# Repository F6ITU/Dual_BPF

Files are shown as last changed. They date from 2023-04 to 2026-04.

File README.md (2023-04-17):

# Alexiares dual BPF for Orion/Anvelina SDR Board

1 to 60 MHz Band pass filter for dual ADC SDR  (Orion class, Anvelina, Red Pitaya)

This pcb serves as RX bandpass for the new generation of Alexiares frontend

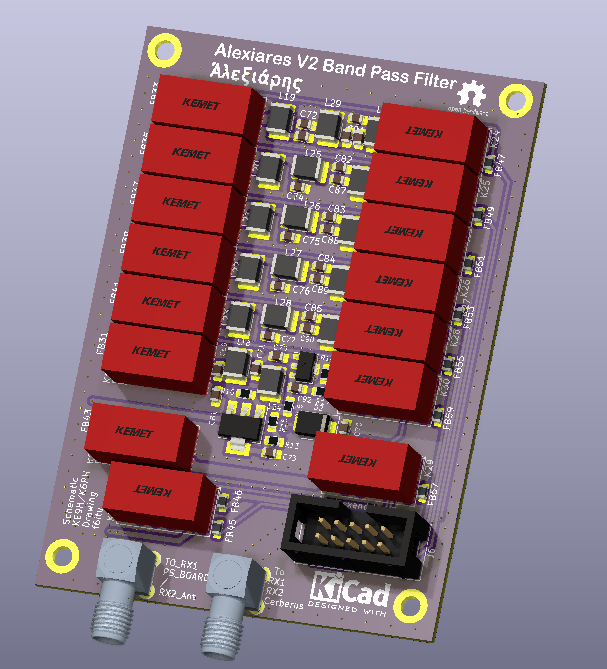
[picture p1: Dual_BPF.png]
Alex BPF V1


It replace the former Alexiares HPF filter and uses the very same SPI bus protocol

Please note that on BPF1  

K23, FB45, FB46, R11, R12, C106 and C93 should NOT be soldered

 (pads 3-10 and 9-4 should be strapped)
 
Signal RX2_GND is not used

BPF2 should be fully assembled, with K23, FB45, FB46, R11, R12, C106 and C93. Signal RX2_GND should be present on J6

(see Alexandrie V2 wirering )

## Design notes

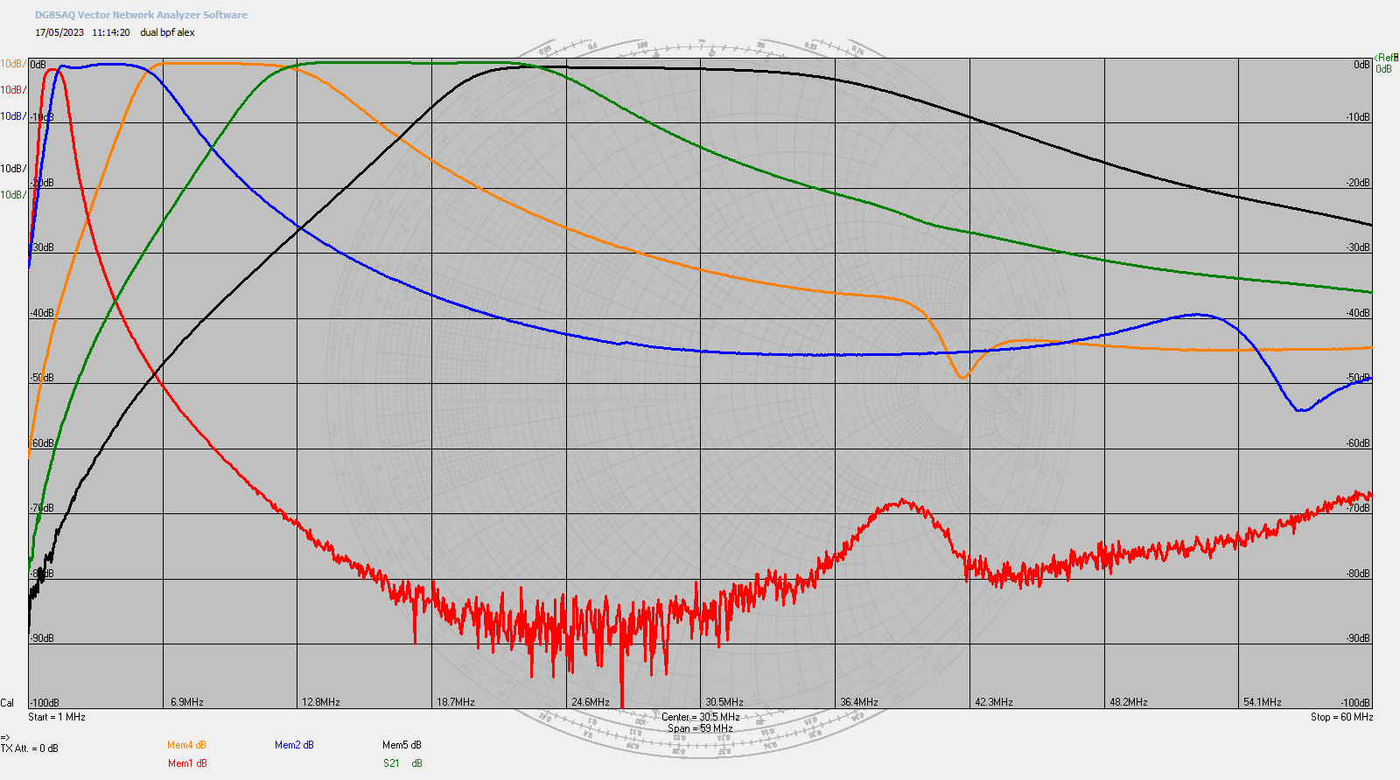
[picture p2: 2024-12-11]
documentation/Dual_bpf_alex_amplitude.png

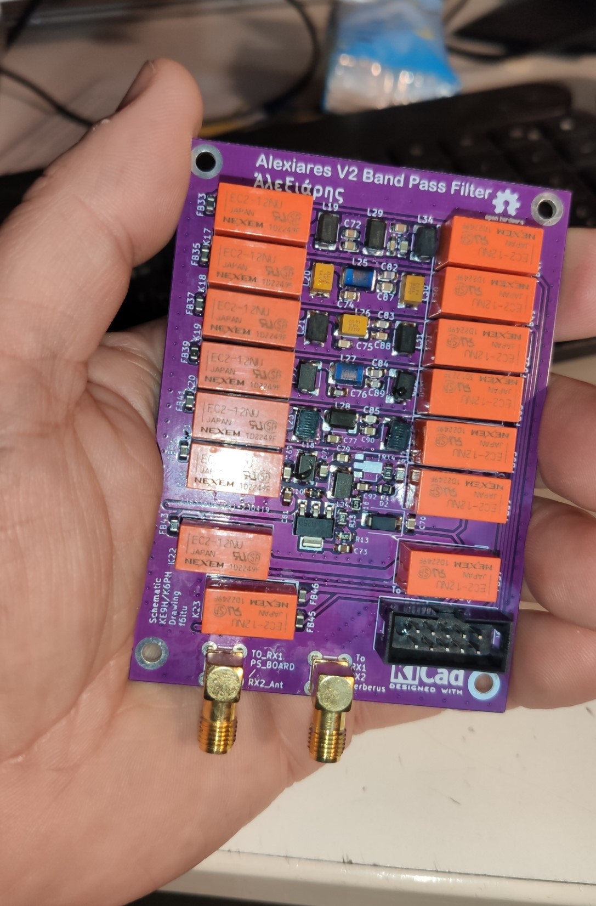
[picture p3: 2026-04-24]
documentation/Dual_bandpass_filter.jpg

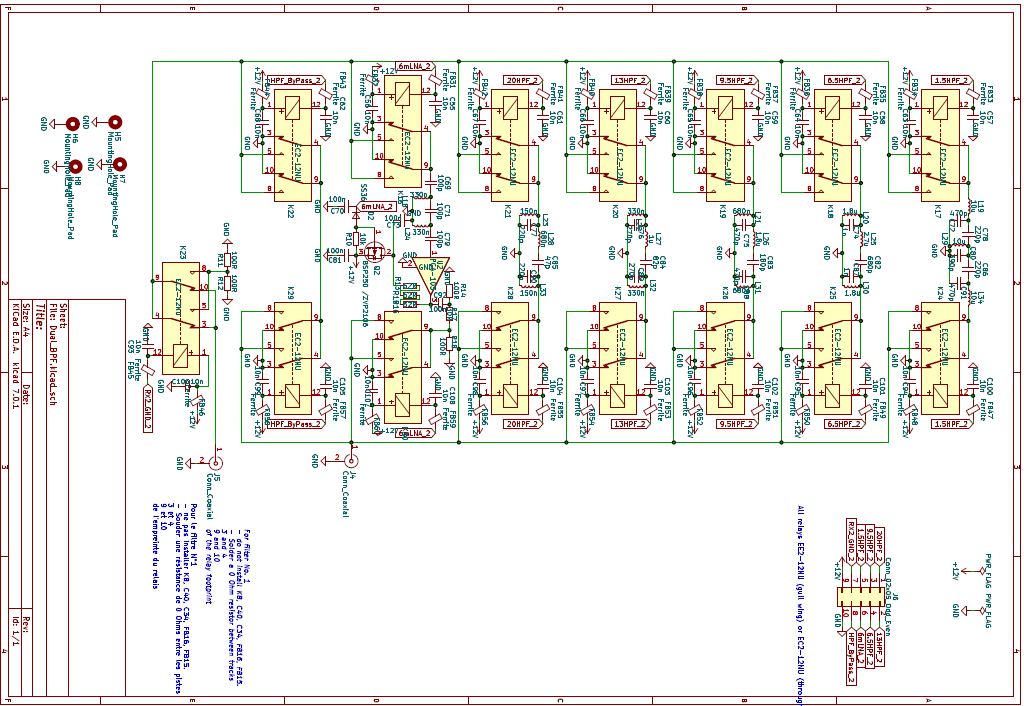
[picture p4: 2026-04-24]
documentation/Dual_bpf.png

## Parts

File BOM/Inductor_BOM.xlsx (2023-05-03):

inductance | ref mouser | form factor | Qty/brd | PU | Price 2 filters
330n | 279-3613CR33M | 1812 | 4 | 0,60 | 4.8 | x8
150n | 994-1812SMS-R15JLC | 1812 | 2 | 2,11 | 8.44 | X4
680n | 807-1812R-681K | 1812 | 3 | 1,88 | 11.28 | x6
1u | 994-1812CS-102XJLC | 1812 | 1 | 1,17 | 2.34 | x2
1.8u | 70-IMC1812RQ1R8J | 1812 | 3 | 0,71 | 4.26 | x6
2.7u | 1812CS-272XJLC (https://www.mouser.fr/ProductDetail/Coilcraft/1812CS-272XJLC?qs=zCSbvcPd3pb%2FoQoml91VxA%3D%3D) | 1812 | 1 | 1,17 | 2.34 | x2
10u | 807-1812R-103J | 1812 | 3 | 2,53 | 15.18 | x6
Relays |  |  | 17
EC-12NU | 80-EC2-12NU |  | 15 | 1,85 | 55.5 | x30.. Envisager x100 à 166€
filters
 | 139-RLP-50 | GP731 |  | 16,33 | 100 | (x10 pour Cerbère et dupli)
semi-conductors
CDSOD323-T03S | 652-CDSOD323-T03S | SOD-323-2 | 1 | 0,62 | 5.48 | (x10 stock)
BSP250 | 771-BSP250135 | SOT-223-3 | 1 | 0,62 | 5.47 | (x10 stock)
PGA103+ | 139-PGA-103 | SOT-89-4 | 1 | 12,54 | 25.08 | x2 | en stock
AFT05MP075NR1 | 841-AFT05MP075NR1 | TO-270-WB-4 | 1 | 19,70 | 39.4
 |  |  |  |  | 279.57 |  | pas nécessaire

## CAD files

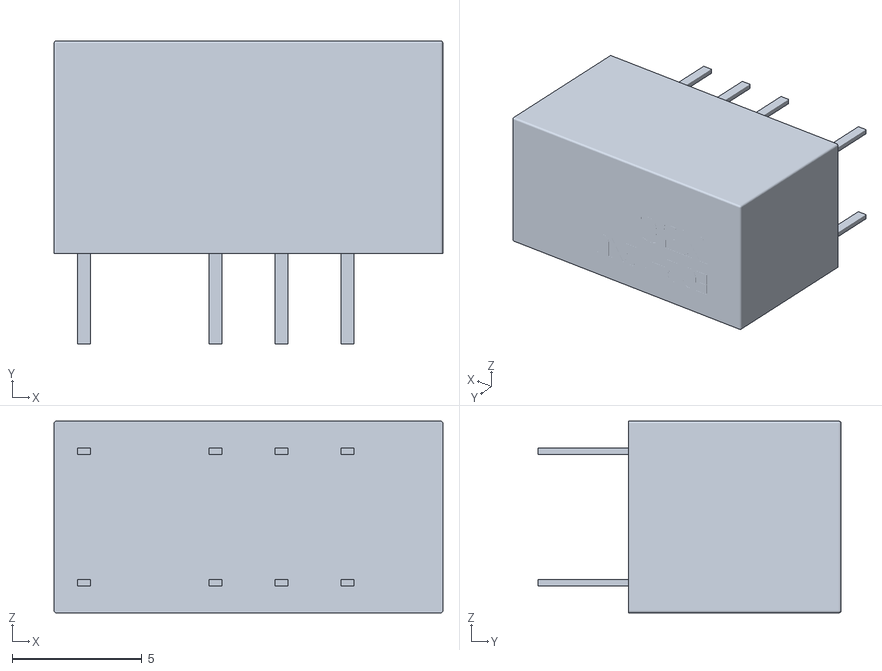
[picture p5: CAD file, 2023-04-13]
documentation/User Library-EC2-12.STL
15.0 x 11.7 x 7.40

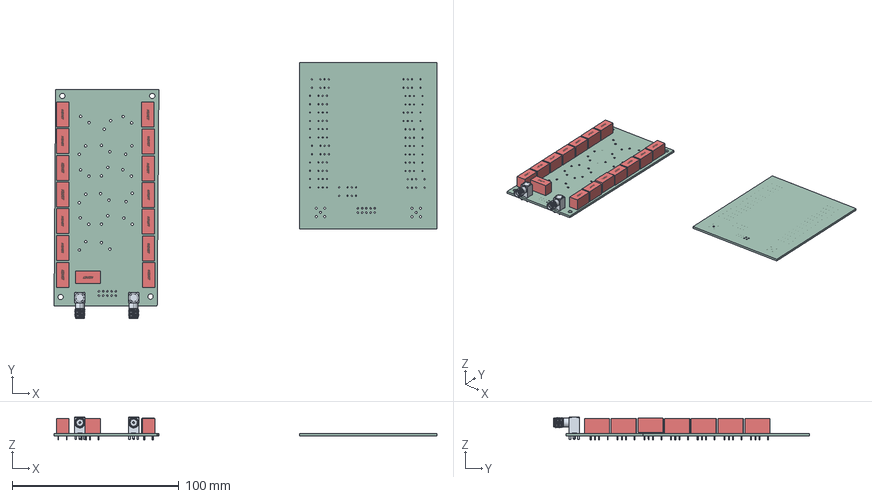
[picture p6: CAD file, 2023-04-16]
Dual_BPF.step
230.0 x 153.5 x 13.8 mm
PCB1
PCB2

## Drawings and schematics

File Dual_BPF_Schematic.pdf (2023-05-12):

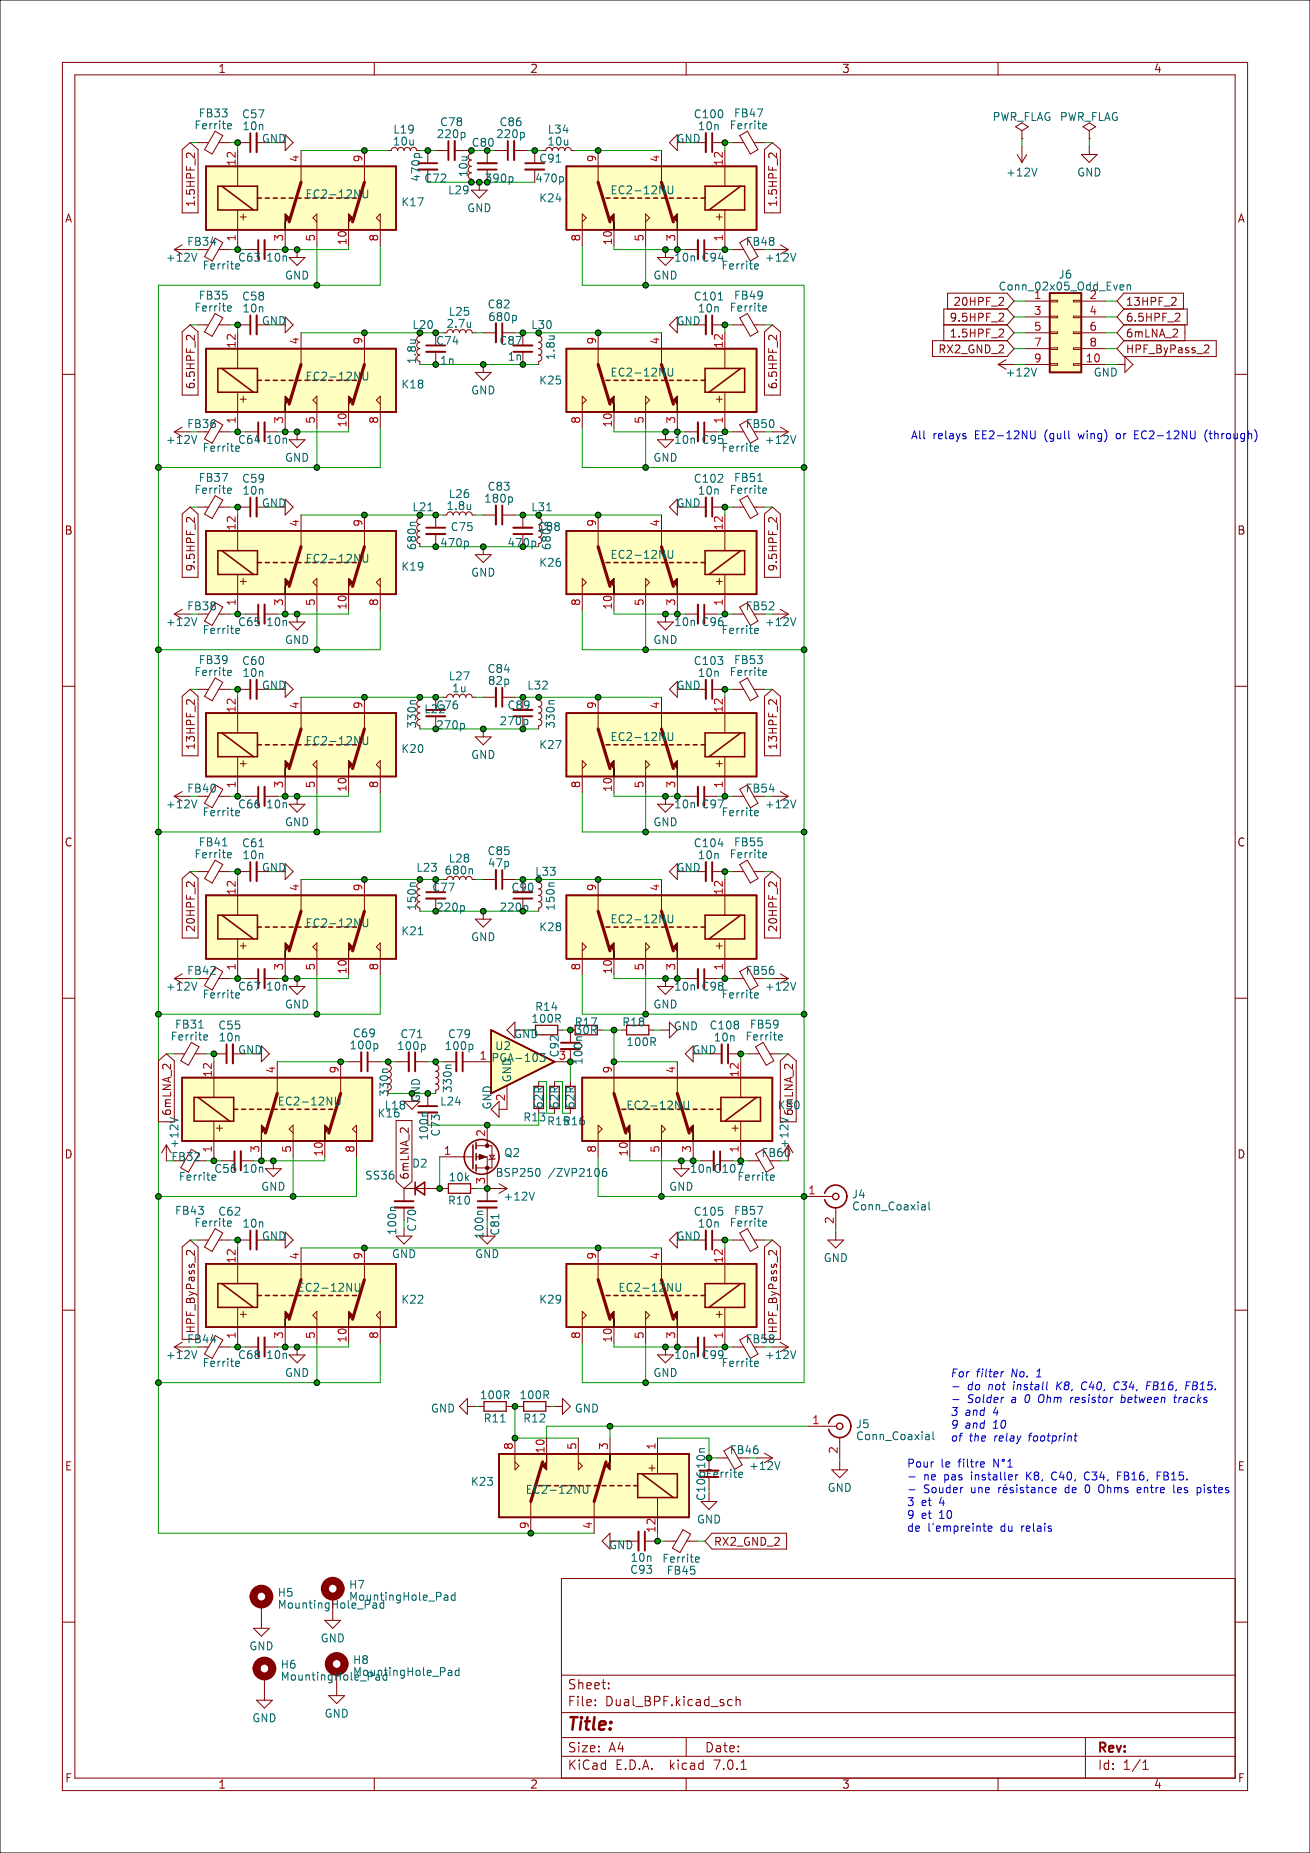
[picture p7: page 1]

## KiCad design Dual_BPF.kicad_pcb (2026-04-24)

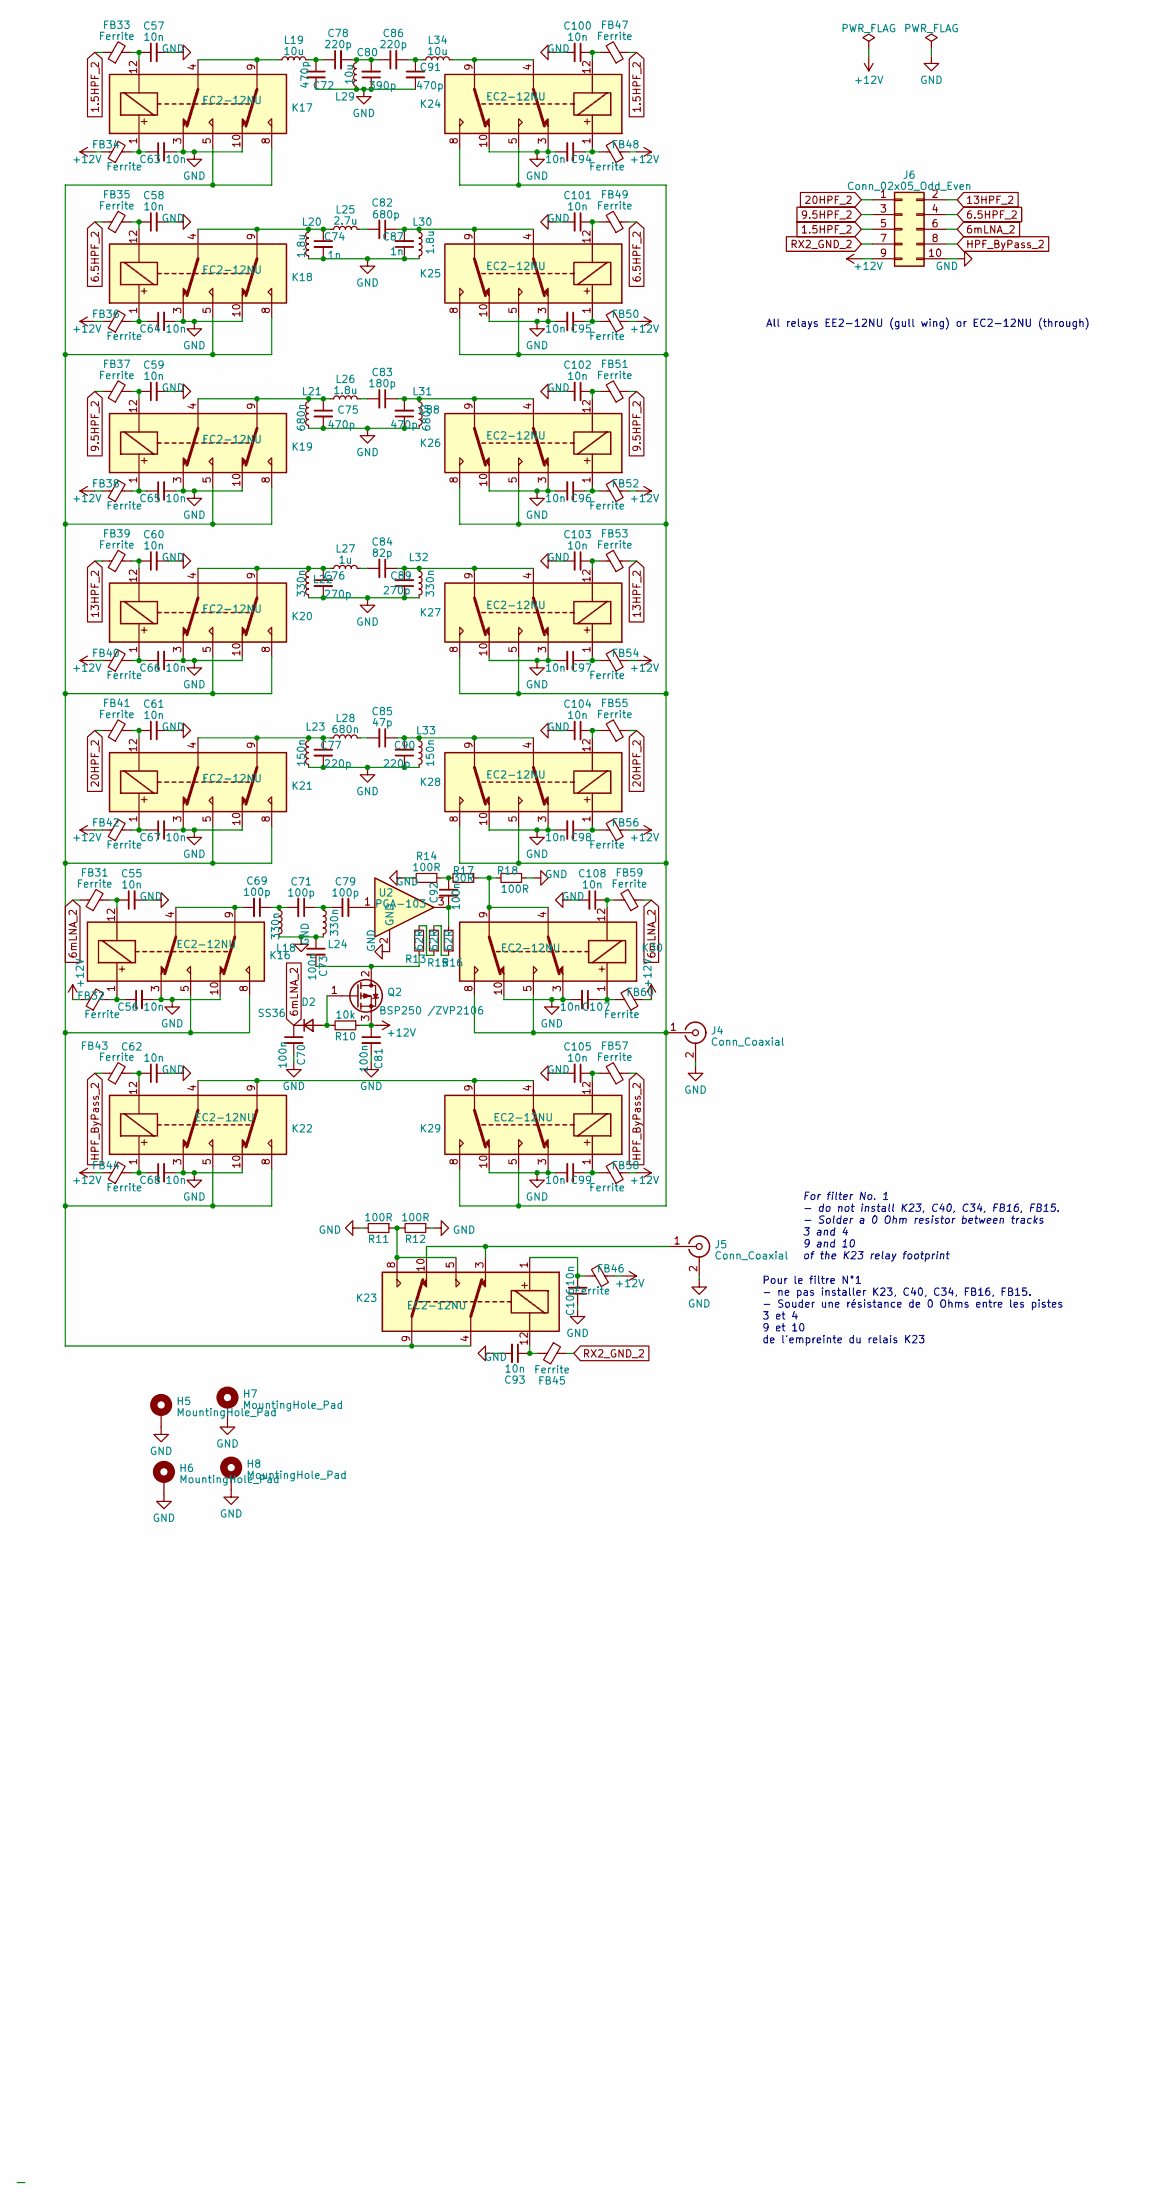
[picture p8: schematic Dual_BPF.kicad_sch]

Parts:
C55, C56, C57, C58, C59, C60, C61, C62, C63, C64, C65, C66, C67, C68, C93, C94, C95, C96, C97, C98, C99, C100, C101, C102, C103, C104, C105, C106, C107, C108: 10n; C_0805_2012Metric_Pad1.18x1.45mm_HandSolder
C69, C71, C79: 100p; C_0805_2012Metric_Pad1.18x1.45mm_HandSolder
C70, C73, C81, C92: 100n; C_0805_2012Metric_Pad1.18x1.45mm_HandSolder
C72, C75, C88, C91: 470p; C_0805_2012Metric_Pad1.18x1.45mm_HandSolder
C74, C87: 1n; C_0805_2012Metric_Pad1.18x1.45mm_HandSolder
C76, C89: 270p; C_0805_2012Metric_Pad1.18x1.45mm_HandSolder
C77, C78, C86, C90: 220p; C_0805_2012Metric_Pad1.18x1.45mm_HandSolder
C80: 390p; C_0805_2012Metric_Pad1.18x1.45mm_HandSolder
C82: 680p; C_0805_2012Metric_Pad1.18x1.45mm_HandSolder
C83: 180p; C_0805_2012Metric_Pad1.18x1.45mm_HandSolder
C84: 82p; C_0805_2012Metric_Pad1.18x1.45mm_HandSolder
C85: 47p; C_0805_2012Metric_Pad1.18x1.45mm_HandSolder
D2: SS36; D_SMB
FB31, FB32, FB33, FB34, FB35, FB36, FB37, FB38, FB39, FB40, FB41, FB42, FB43, FB44, FB45, FB46, FB47, FB48, FB49, FB50, FB51, FB52, FB53, FB54, FB55, FB56, FB57, FB58, FB59, FB60: Ferrite; L_0805_2012Metric
H5, H6, H7, H8: MountingHole_Pad; MountingHole_3.2mm_M3_ISO14580_Pad
J4, J5: Conn_Coaxial; SMA_PINS
J6: Conn_02x05_Odd_Even; IDC-Header_2x05_P2.54mm_Vertical
K16, K17, K18, K19, K20, K21, K22, K23, K24, K25, K26, K27, K28, K29, K30: EC2-12NU; Relay_DPDT_Kemet_EC2
L18, L22, L24, L32: 330n; L_1812_4532Metric_Pad1.30x3.40mm_HandSolder
L19, L29, L34: 10u; L_1812_4532Metric_Pad1.30x3.40mm_HandSolder
L20, L26, L30: 1.8u; L_1812_4532Metric_Pad1.30x3.40mm_HandSolder
L21, L28, L31: 680n; L_1812_4532Metric_Pad1.30x3.40mm_HandSolder
L23, L33: 150n; L_1812_4532Metric_Pad1.30x3.40mm_HandSolder
L25: 2.7u; L_1812_4532Metric_Pad1.30x3.40mm_HandSolder
L27: 1u; L_1812_4532Metric_Pad1.30x3.40mm_HandSolder
Q2: BSP250 /ZVP2106; SOT-223-3_TabPin2
R10: 10k; R_0805_2012Metric_Pad1.20x1.40mm_HandSolder
R11, R12, R14, R18: 100R; R_0805_2012Metric_Pad1.20x1.40mm_HandSolder
R13, R15, R16: 62R; R_0805_2012Metric_Pad1.20x1.40mm_HandSolder
R17: 30R; R_0805_2012Metric_Pad1.20x1.40mm_HandSolder
U2: PGA-103; SOT-89-3

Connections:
1.5HPF_2: FB33.1, FB47.1, J6.5
6.5HPF_2: FB35.1, FB49.1, J6.4
6mLNA_2: C70.1, D2.1 (K), FB31.1, FB59.1, J6.6
9.5HPF_2: FB37.1, FB51.1, J6.3
13HPF_2: FB39.1, FB53.1, J6.2
20HPF_2: FB41.1, FB55.1, J6.1
+12V: C81.1, FB32.1, FB34.1, FB36.1, FB38.1, FB40.1, FB42.1, FB44.1, FB46.1, FB48.1, FB50.1, FB52.1, FB54.1, FB56.1, FB58.1, FB60.1, J6.9, Q2.3 (S), R10.1
GND: C55.2, C56.2, C57.2, C58.2, C59.2, C60.2, C61.2, C62.2, C63.2, C64.2, C65.2, C66.2, C67.2, C68.2, C70.2, C72.2, C73.1, C74.2, C75.2, C76.2, C77.2, C80.1, C81.2, C87.1, C88.1, C89.1, C90.1, C91.2, C93.2, C94.2, C95.2, C96.2, C97.2, C98.2, C99.2, C100.2, C101.2, C102.2, C103.2, C104.2, C105.2, C106.1, C107.2, C108.2, H5.1, H6.1, H7.1, H8.1, J4.2 (Ext), J5.2 (Ext), J6.10, K16.3, K16.10, K17.3, K17.10, K18.3, K18.10, K19.3, K19.10, K20.3, K20.10, K21.3, K21.10, K22.3, K22.10, K24.3, K24.10, K25.3, K25.10, K26.3, K26.10, K27.3, K27.10, K28.3, K28.10, K29.3, K29.10, K30.3, K30.10, L18.2, L20.1, L21.1, L22.1, L23.1, L24.2, L29.2, L30.2, L31.2, L32.2, L33.2, R11.2, R12.1, R14.2, R18.1, U2.2 (GND)
HPF_ByPass_2: FB43.1, FB57.1, J6.8
unnamed: C55.1, FB31.2, K16.12
unnamed: C56.1, FB32.2, K16.1
unnamed: C57.1, FB33.2, K17.12
unnamed: C58.1, FB35.2, K18.12
unnamed: C59.1, FB37.2, K19.12
unnamed: C60.1, FB39.2, K20.12
unnamed: C61.1, FB41.2, K21.12
unnamed: C62.1, FB43.2, K22.12
unnamed: C63.1, FB34.2, K17.1
unnamed: C64.1, FB36.2, K18.1
unnamed: C65.1, FB38.2, K19.1
unnamed: C66.1, FB40.2, K20.1
unnamed: C67.1, FB42.2, K21.1
unnamed: C68.1, FB44.2, K22.1
unnamed: C69.1, C71.2, L18.1
unnamed: C69.2, K16.4, K16.9
unnamed: C71.1, C79.2, L24.1
unnamed: C72.1, C78.1, L19.1
unnamed: C74.1, K18.4, K18.9, L20.2, L25.1
unnamed: C75.1, K19.4, K19.9, L21.2, L26.1
unnamed: C76.1, K20.4, K20.9, L22.2, L27.1
unnamed: C77.1, K21.4, K21.9, L23.2, L28.1
unnamed: C78.2, C80.2, C86.1, L29.1
unnamed: C79.1, U2.1
unnamed: C82.1, C87.2, K25.4, K25.9, L30.1
unnamed: C82.2, L25.2
unnamed: C83.1, C88.2, K26.4, K26.9, L31.1
unnamed: C83.2, L26.2
unnamed: C84.1, C89.2, K27.4, K27.9, L32.1
unnamed: C84.2, L27.2
unnamed: C85.1, C90.2, K28.4, K28.9, L33.1
unnamed: C85.2, L28.2
unnamed: C86.2, C91.1, L34.2
unnamed: C92.1, R14.1, R17.2
unnamed: C92.2, R16.2, U2.3
unnamed: C93.1, FB45.2, K23.12
unnamed: C94.1, FB48.2, K24.1
unnamed: C95.1, FB50.2, K25.1
unnamed: C96.1, FB52.2, K26.1
unnamed: C97.1, FB54.2, K27.1
unnamed: C98.1, FB56.2, K28.1
unnamed: C99.1, FB58.2, K29.1
unnamed: C100.1, FB47.2, K24.12
unnamed: C101.1, FB49.2, K25.12
unnamed: C102.1, FB51.2, K26.12
unnamed: C103.1, FB53.2, K27.12
unnamed: C104.1, FB55.2, K28.12
unnamed: C105.1, FB57.2, K29.12
unnamed: C106.2, FB46.2, K23.1
unnamed: C107.1, FB60.2, K30.1
unnamed: C108.1, FB59.2, K30.12
unnamed: D2.2 (A), Q2.1 (G), R10.2
unnamed: J4.1 (In), K24.5, K24.8, K25.5, K25.8, K26.5, K26.8, K27.5, K27.8, K28.5, K28.8, K29.5, K29.8, K30.5, K30.8
unnamed: J5.1 (In), K23.3, K23.10
unnamed: K16.5, K16.8, K17.5, K17.8, K18.5, K18.8, K19.5, K19.8, K20.5, K20.8, K21.5, K21.8, K22.5, K22.8, K23.4, K23.9
unnamed: K17.4, K17.9, L19.2
unnamed: K22.4, K22.9, K29.4, K29.9
unnamed: K23.5, K23.8, R11.1, R12.2
unnamed: K24.4, K24.9, L34.1
unnamed: K30.4, K30.9, R17.1, R18.2
unnamed: C73.2, Q2.2 (D), R13.1
unnamed: R13.2, R15.1
unnamed: R15.2, R16.1
RX2_GND_2: FB45.1, J6.7

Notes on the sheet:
Pour le filtre N°1 - ne pas installer K23, C40, C34, FB16, FB15. - Souder une résistance de 0 Ohms entre les pistes 3 et 4 9 et 10 de l'empreinte du relais K23
All relays EE2-12NU (gull wing) or EC2-12NU (through)
For filter No. 1 - do not install K23, C40, C34, FB16, FB15. - Solder a 0 Ohm resistor between tracks 3 and 4 9 and 10 of the K23 relay footprint

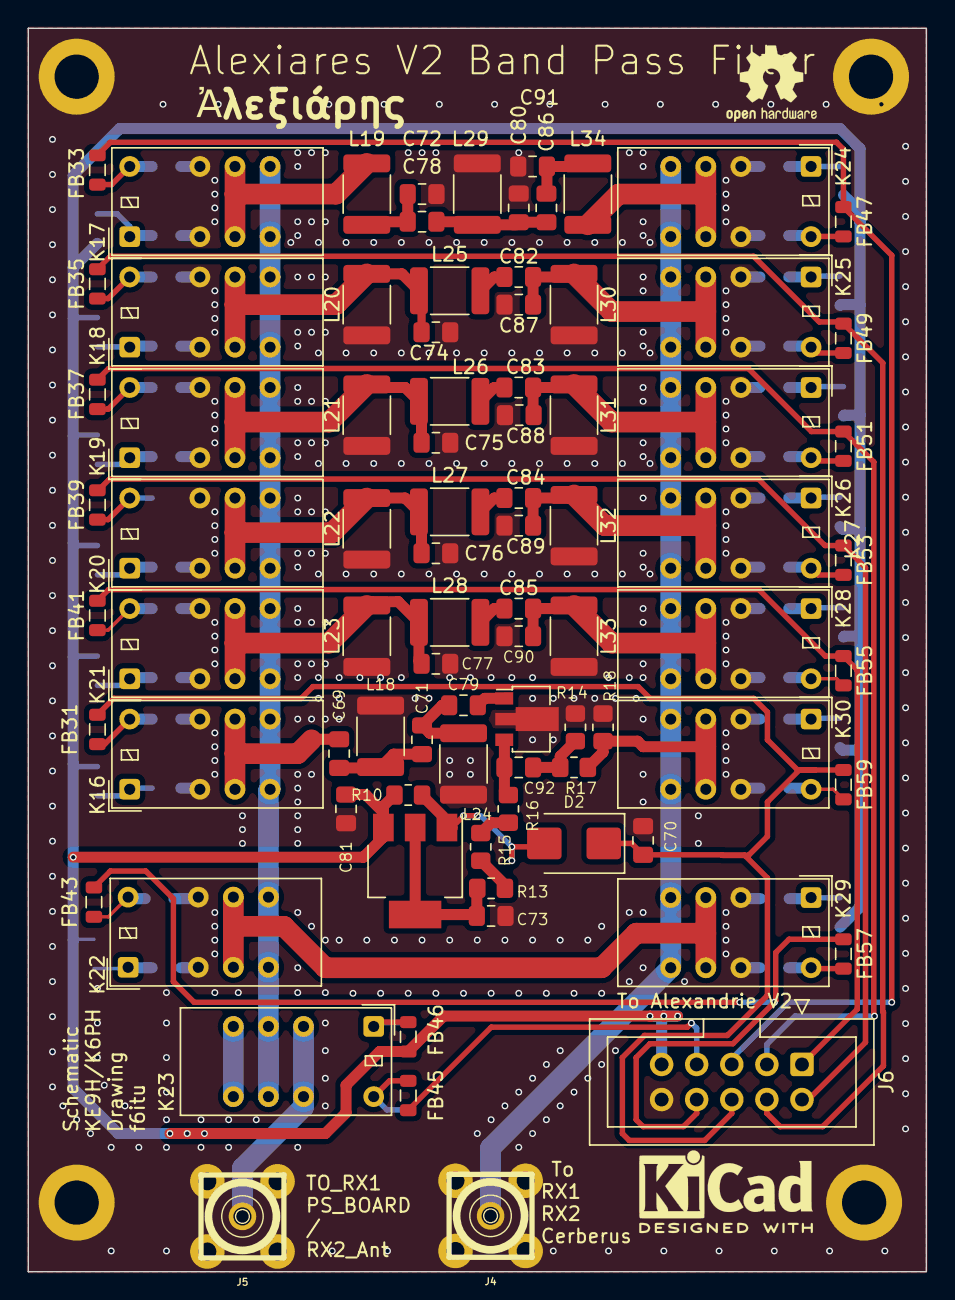
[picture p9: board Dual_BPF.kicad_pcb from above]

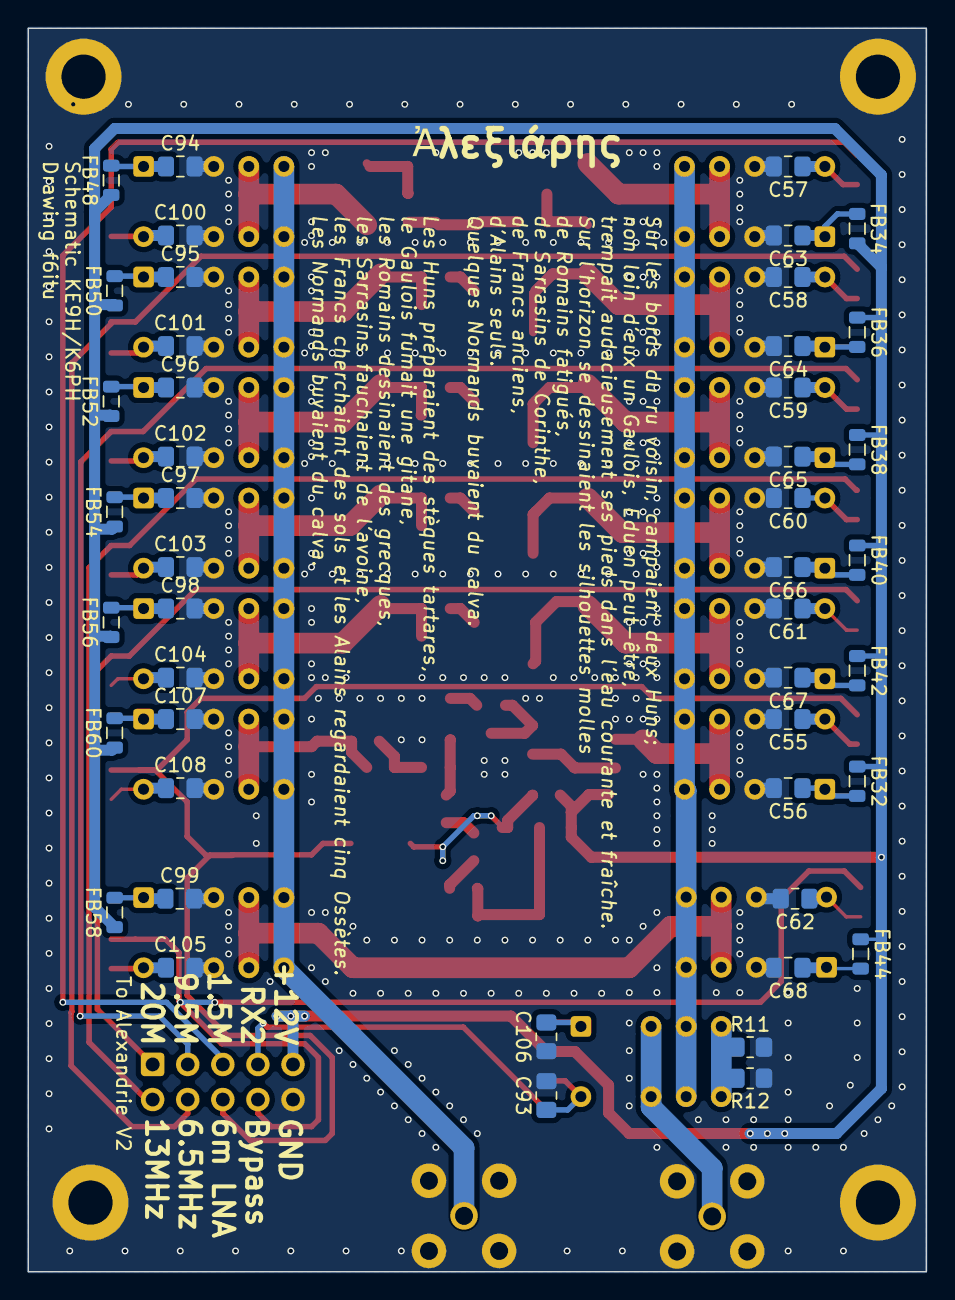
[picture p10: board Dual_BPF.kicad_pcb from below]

Board: 2 copper layers, 65.0 x 90.0 mm, 135 parts (46 on the bottom side), 73 nets.

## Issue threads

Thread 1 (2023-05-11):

Dual_BPF_Schematic.pdf

DH1KLM, 2023-05-11:
Hi Marc,

schematic Dual_BPF_Schematic.pdf is identical to AlexV2_schematic.pdf.

Or have I misunderstood something?

F6ITU, 2023-05-11:
Oh, so sorry, Sigi

By default, Kicad keeps the same path when « printing to pdf » the schematic… and when I updated the repository, I didn’t check the containt.

Github has been fixed

Thnks again
Marc

Ps : Kicad version of Aries has been finished yesterday. I will modify some small details, but so far, it’s probably a « real clone » of LA2NI’s board
https://github.com/F6ITU/K_Aries

… and I’m beginning the kicad for Munin 400. I’ll try to build the « dual bpf » next week to measure the « real life » filter

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

DH1KLM, 2023-05-14:
I'm already curious about the Dual BPF.

F6ITU, 2023-05-18:
Hi Sigi

These are the « raw » real filter measurements.
I didn’t solder the LNA MMIC, that’s why you cannot see the 6m band (but if you absolutely need them, I will build a specific test setup asap)

So far, results are  identical compared with the bpf filter used in the Anan 7000DLE and 8000DLE. No more, no less.

The upper slope of each filter  is not significant, as in the « real life », you should add the Q of the LPF « tx » filter which is always in series with the RX bpf

From a practical point of view, results cannot be compared with the « old fashioned » HPF + BPF eliptical filters of the former Alexiares frontend. This bpf filter is considerably easier to build and the crossover frequencies are perfectly choosen for people involved in ham radio
But for people listening for wide spread spectrum transmissions, frequencies located in the « crossover zone », wishing to have a real « high end » filter with a rejection of more than 80 -90 dB, and looking for a variable bandpass filter using combination of different hpf and lpf filters, nothing can replace the « alex old style ».

In other words, I think my next Angelia and Anvelina boards will  use the old hpf for RX1 path and one SMD bpf for RX2 path (as the Alex protocol cannot combine more than one lpf  during RX). This way, I’ll have a «more spurious free » RX2 path with grounding of the second adc when transmiting, and a high performance RX HPF+BPF filter in the RX1 path. The new Alexandrie V2 board can handle this kind of configuration.

When Apache labs decided to abandon the hpf-bpf architecture and replace it with the SMD based bpf, it  was for 2 reasons :

  *   It cost a lot less than the hpf with less tuning hassle
  *   Very few ham where able to understand this architecture and were using Alex configuration by default, as they only whist to use an OpenHPSDR architecture like any other analog transceiver.
So, why shouldn’t they choose the « easy way » ?

I definitely should test this bpf filters combination on my Red Pitaya rigs…. They are the perfect candidates for this kind of frontend

Have a nice day, Sigi
73’
Marc f6itu

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

Closed 2023-05-14.

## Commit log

2023-04-13 first commit, schematic partially designed
    [Dual_BPF.kicad_pcb, Dual_BPF.kicad_sch, User Library-EC2-12.STL]
2023-04-16 work in progress, 2 different pcb
    [Dual_BPF.kicad_pcb, Dual_BPF.kicad_sch, Dual_BPF.step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]
2023-04-17 SMD version RTM 1.0, toroid version deleted
    [Dual_BPF.kicad_pcb, Dual_BPF.kicad_sch]
2023-04-17 silk done
    [Dual_BPF.kicad_pcb]
2023-04-17 picture, iBom, BOM, pdf Schematic added
    [Dual_BPF-B_Cu.gbl, Dual_BPF-B_Mask.gbs, Dual_BPF-B_Paste.gbp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]
2023-04-18 Elsie simulations added
    [ElsieConfiguration.CFG]
2023-04-19 added an S2P directory with simulation datas
    [ElsieConfiguration.CFG]
2023-05-03 fix some silkscreen errors, new gerber
    [Dual_BPF-B_Cu.gbl, Dual_BPF-B_Mask.gbs, Dual_BPF-B_Paste.gbp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]
2023-05-11 new schematic pdf file, thank you, Sigi
2023-05-12 small mods on schematic comments
    [Dual_BPF.kicad_sch]
2024-12-11 minor changes and new iBom
    [Dual_BPF.kicad_pcb, Dual_BPF.kicad_sch, ElsieConfiguration.CFG]
2026-04-24 kicad 10 updated, wiki added
    [Dual_BPF.kicad_pcb, Dual_BPF.kicad_sch]
